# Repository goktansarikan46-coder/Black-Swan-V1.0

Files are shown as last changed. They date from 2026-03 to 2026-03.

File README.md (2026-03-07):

# Black-Swan V1.0 | Wireless Biomedical & Seismic Sensor Node

Black-Swan V1.0, saha verilerini işlemek ve uzun menzilli kablosuz ağlar üzerinden aktarmak için geliştirdigim, düşük güç tüketimli bir "Edge" sensör düğümüdür. Proje kapsamında, biyomedikal sinyal işleme (AFE) yeteneklerini savunma sanayii standartlarında RF güvenilirliği ile tek bir PCB üzerinde birlestirmeyi hedefledim.

## Teknik Özellikler

* **Mikrodenetleyici (MCU):** STM32L431RCT6 (Ultra-Low Power ARM Cortex-M4).
* **Kablosuz Haberleşme (RF):** SX1278 LoRa modülü entegrasyonu ve 50 $\Omega$ empedans uyumlu SMA anten çıkışı.
* **Analog Ön Uç (AFE):** EKG, EMG veya sismik veriler için optimize edilmiş 3-Op-Amp enstrümantasyon amplifikatörü.
* **Atalet Sensörü (IMU):** 6-eksenli hareket takibi için entegre MPU-6050.
* **Güç Yönetimi:** USB-C üzerinden besleme hattı ve gürültü regülasyonu için molded güç indüktörü (L1).

## Proje Yapısı

* `/Hardware`: KiCad şematik (.kicad_sch) ve PCB (.kicad_pcb) tasarım dosyaları.
* `/Hardware/BOM`: Malzeme listesi ve bileşen detayları.
* `/Docs`: Tasarım raporları ve 3D render görselleri.

## Tasarım Kararları

RF bütünlüğü ve analog sinyal kalitesini korumak adına genel amaçlı genişleme portlarını V2.0 sürümüne planladım.

---
**Hazırlayan:** Göktan Sarıkan (Yıldız Teknik Üniversitesi)
**Tarih:** Mart 2026

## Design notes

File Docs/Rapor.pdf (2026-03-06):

Black-Swan V1.0 | Kablosuz Biyomedikal ve Sismik Sensör Platformu

Bir süredir üzerinde çalıştığım ve tasarım süreçlerini tamamen mühürlediğim Black-Swan V1.0 projesini sonunda tamamladım. Bir biyomedikal mühendisliği öğrencisi olarak, hem tıbbi cihaz teknolojilerini hem de kablosuz haberleşme altyapısını tek bir PCB'de birleştirmeyi hedefledim.

Neyi Hedefledim?

Bu kartı tasarlarken temel amacım; sahadan gelen çok düşük genlikli analog verileri (EKG, EMG veya sismik titreşimler) yüksek hassasiyetle işleyip, LoRa teknolojisiyle kilometrelerce öteye aktarabilen bir "uç düğüm" (edge node) oluşturmaktı.

Teknik Detaylar

- Ana Kontrolcü: Düşük güç tüketimi ve performans dengesi nedeniyle STM32L431RCT6 mimarisini tercih ettim.
- Kablosuz Haberleşme: Uzun menzilli veri aktarımı için SX1278 LoRa transiver modülünü entegre ettim. Sinyal kalitesini (RF integrity) korumak adına standart buton yapılarından kaçınarak doğrudan SMA anten konnektörü kullandım.
- Analog Ön Uç (AFE): Gürültü faktörünü minimize etmek için 3-op-amp yapısında bir enstrümantasyon amplifikatörü katmanı kurguladım. Bu sayede mikrovolt seviyesindeki verileri bile stabil şekilde dijitalleştirebiliyorum.
- Hareket Takibi: Kart üzerindeki MPU-6050 ile 6-eksenli hareket verisini alarak, aktif stabilizasyon projelerim için gerekli veri akışını sağladım.
- Güç Hattı: Modernite ve dayanıklılık için USB-C girişini kullandım; hattaki gürültüyü süzmek adına da tasarıma molded güç indüktörü (L1) ekleyerek regülasyon katmanını güçlendirdim.

Tasarım ve Planlama

V1.0 sürümünde, sistemin ana fonksiyonel bloklarının (LoRa, IMU ve AFE) en yüksek stabilitede çalışmasına odaklanarak genel amaçlı genişleme portlarını bir sonraki sürüme bıraktım.

Mart 2026 itibarıyla kartın tüm elektriksel ve 3D tasarım süreçleri bitti; artık üretim ve kodlama aşamasına geçiyorum. Gelişmeleri paylaşmaya devam edeceğim.

PCB Tasarımı:

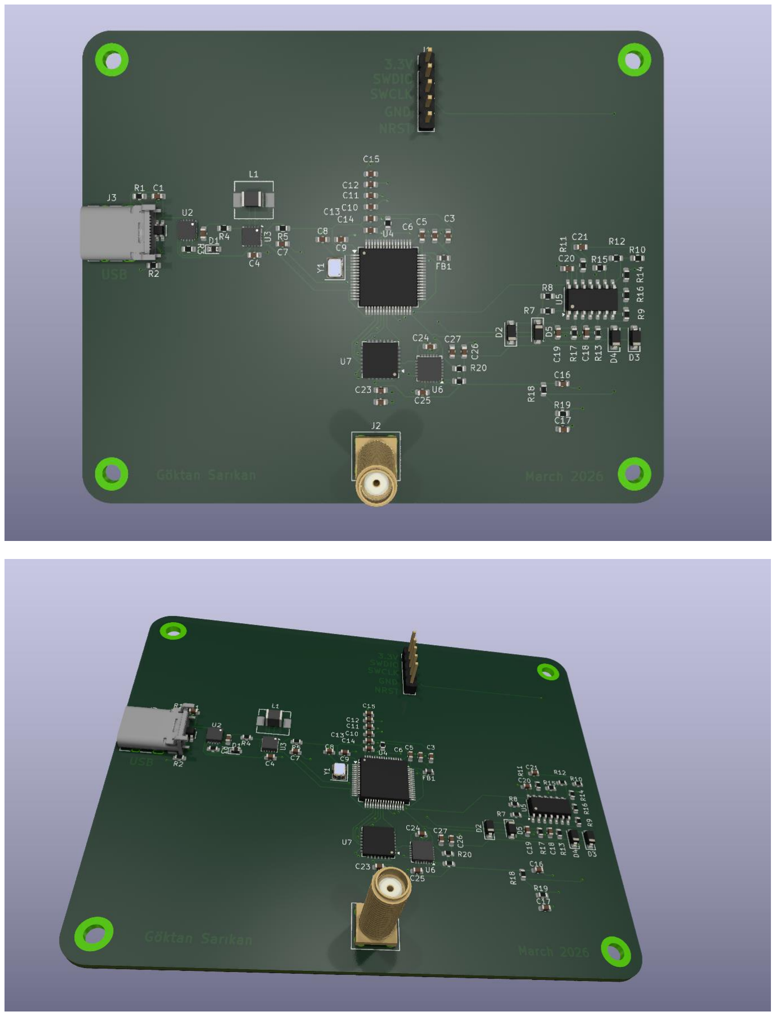
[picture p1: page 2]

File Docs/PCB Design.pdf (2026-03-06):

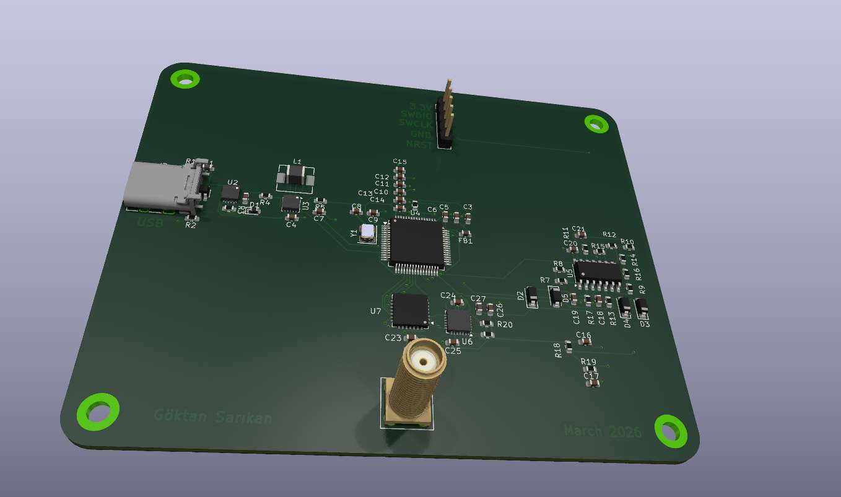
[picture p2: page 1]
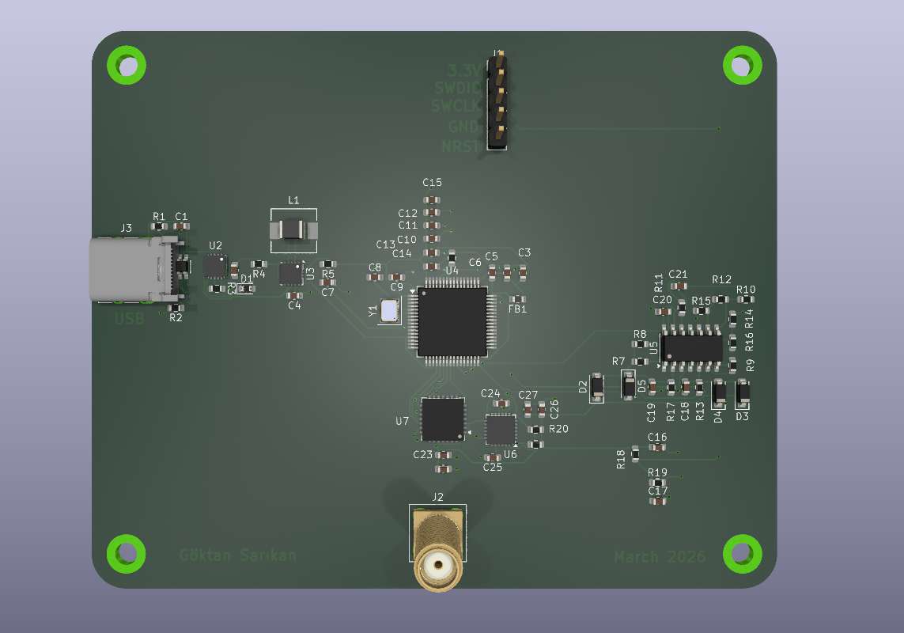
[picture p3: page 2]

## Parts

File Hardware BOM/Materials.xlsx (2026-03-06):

 | Adet | Değer / Parça No | Footprint (Kılıf) | Açıklama
U4 | 1 | STM32L431RCT6 | LQFP-64 | Ana Kontrolcü (MCU), Ultra-Low Power ARM Cortex-M4.
U7 | 1 | SX1278 | SMD Module / QFN | LoRa Kablosuz Haberleşme Modülü (433/470 MHz).
U6 | 1 | MPU-6050 | QFN-24 | 6-Eksenli İvmeölçer ve Jiroskop (IMU).
U5 | 1 | Instrumentation Amp | SOIC-14 / SOIC-16 | 3-Op-Amp Yapısında Analog Ön Uç (AFE).
L1 | 1 | Power Inductor | SMD (Molded) | USB Güç Filtreleme İndüktörü.
Y1 | 1 | Crystal | SMD-3225 | STM32 İçin Harici Kristal Osilatör.
J1 | 1 | SWD Header | 1x05 Pin Header (2.54mm) | Programlama ve Debug Arayüzü (VCC, CLK, GND, DIO, RST).
J2 | 1 | SMA Connector | SMA Edge Mount / Vertical | LoRa Anten Çıkışı (Koaksiyel).
J3 | 1 | USB-C Connector | USB-C 16-Pin | Güç Girişi ve Data Bağlantısı.
R20, R21 | 2 | 4.7k | 0603 / 0805 | I2C Hattı Pull-Up Dirençleri.
C22, C26 | 2 | 100nF | 0603 / 0805 | Dekuplaj Kapasitörleri (Seramik).
C23, C27 | 2 | 10uF | 0603 / 0805 | Güç Filtreleme Kapasitörleri (Tantal veya MLCC).
D1-D5 | 5 | 1N4148 | SOD-123 / SOD-323 | Genel Amaçlı Sinyal Diyotları.
FB1 | 1 | Ferrite Bead | O805 | Gürültü Filtreleme İçin Ferrit Boncuk.

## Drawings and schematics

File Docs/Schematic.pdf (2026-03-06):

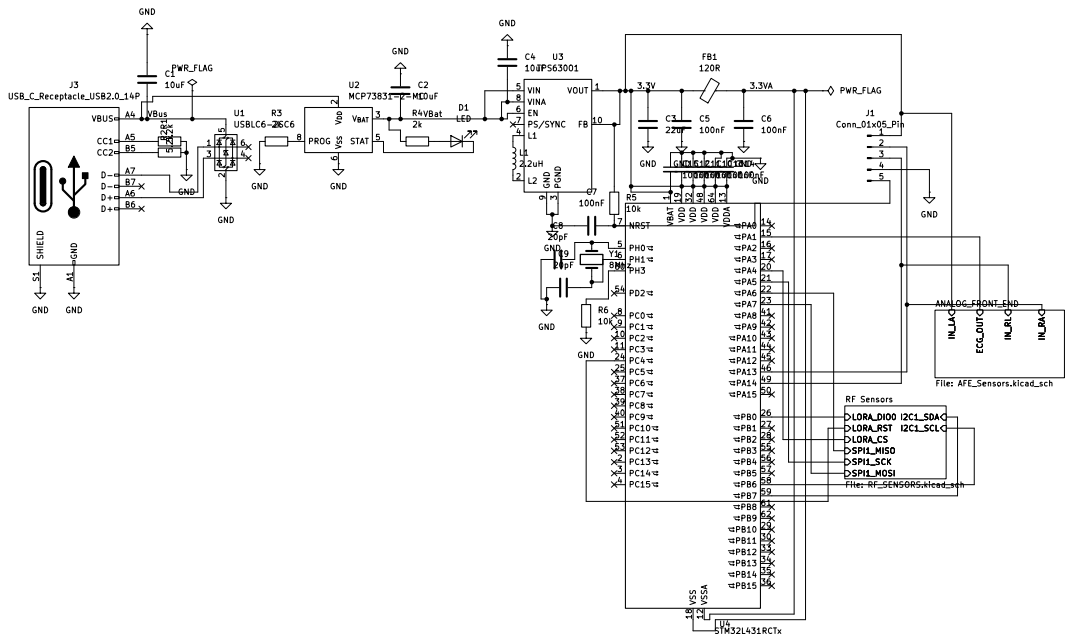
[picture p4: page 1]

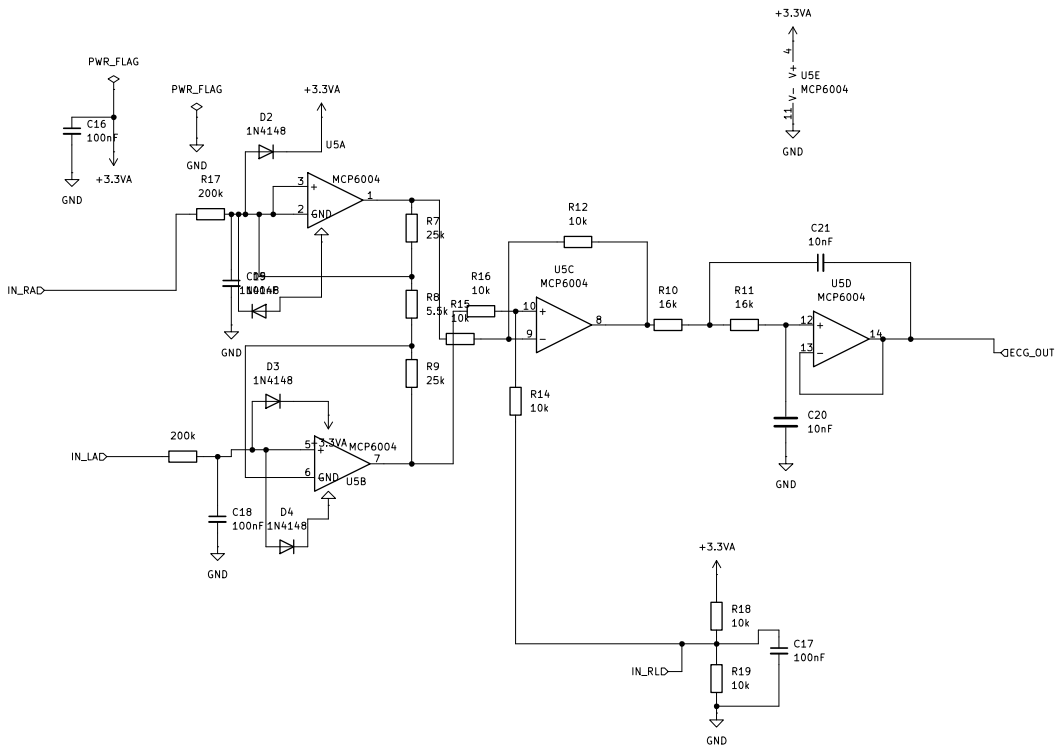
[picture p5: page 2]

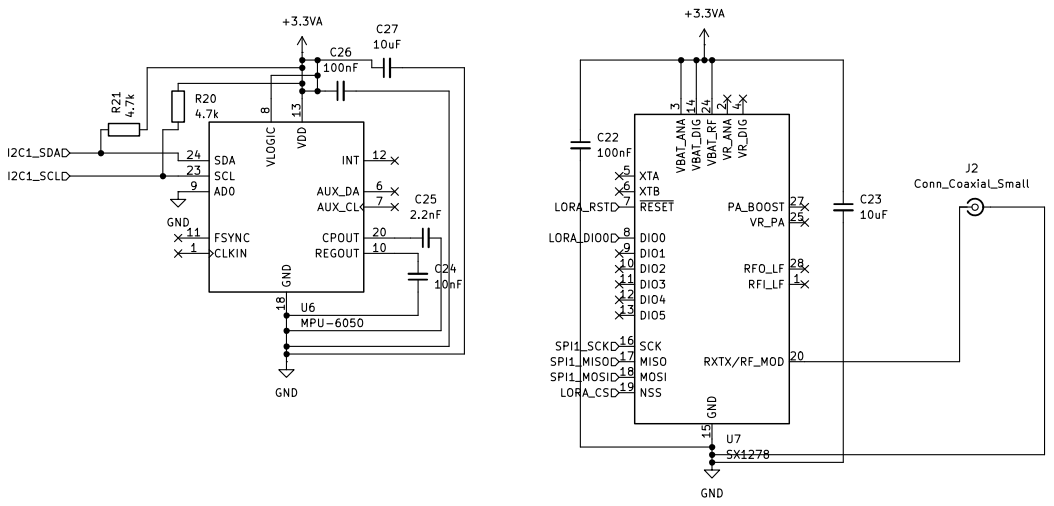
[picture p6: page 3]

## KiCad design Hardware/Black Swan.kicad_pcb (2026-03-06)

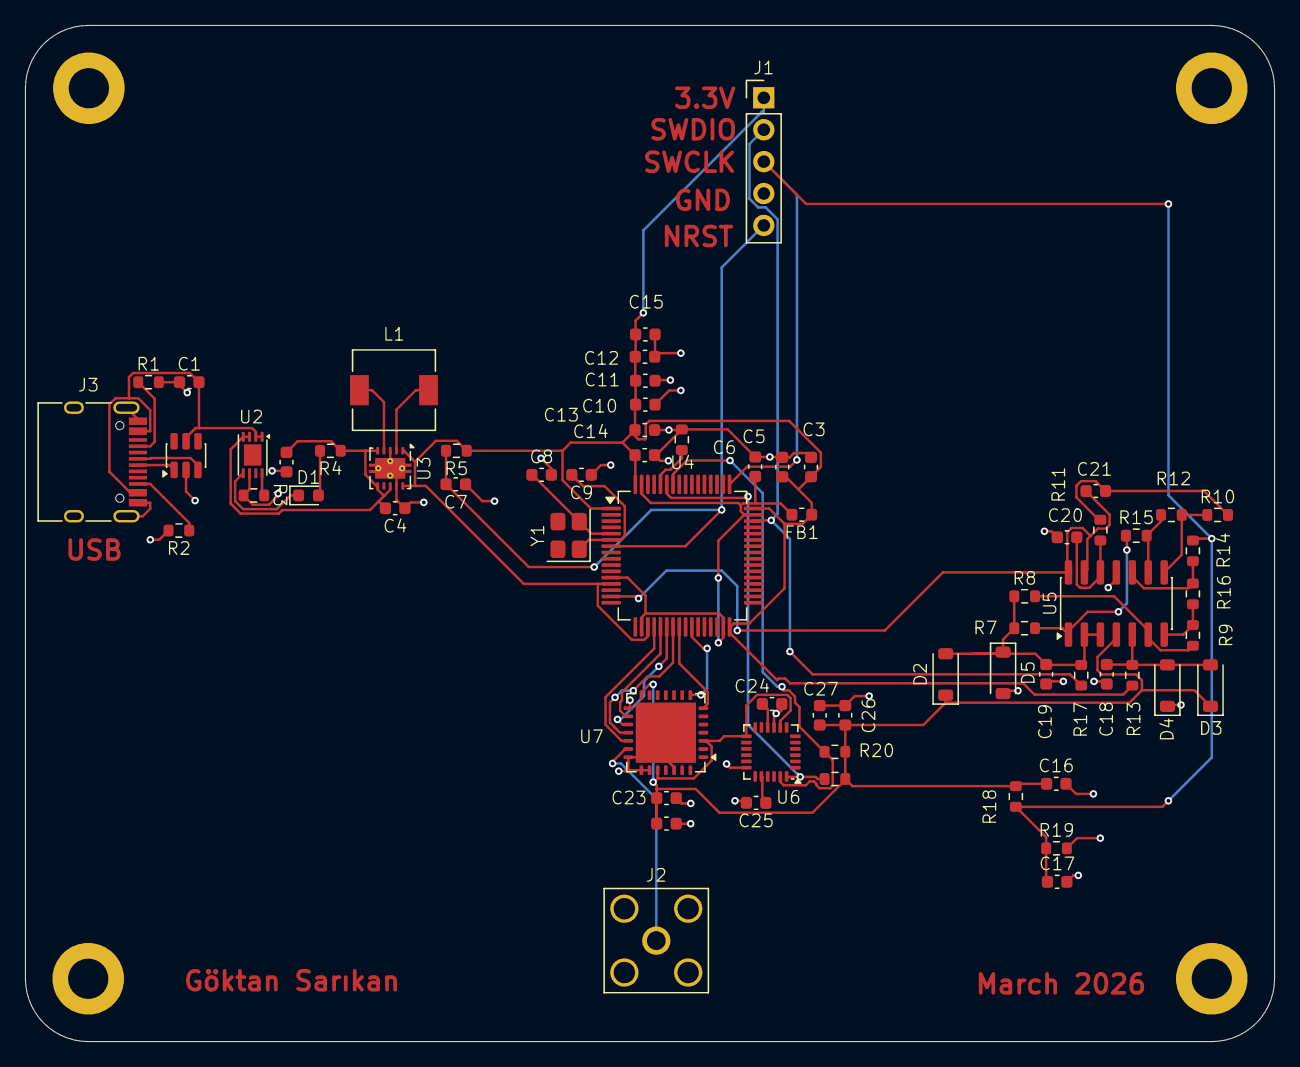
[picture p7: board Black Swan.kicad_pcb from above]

Board: 2 copper layers, 99.4 x 80.9 mm, 66 parts (0 on the bottom side), 43 nets.

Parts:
C1, C2, C4, C23, C27: 10uF; C_0603_1608Metric
C3: 22uF; C_0603_1608Metric
C5, C6, C7, C10, C11, C12, C13, C14, C15, C16, C17, C18, C19, C22, C26: 100nF; C_0603_1608Metric
C8, C9: 20pF; C_0603_1608Metric
C20, C21, C24: 10nF; C_0603_1608Metric
C25: 2.2nF; C_0603_1608Metric
D1: LED; D_0603_1608Metric
D2, D3, D4, D5: 1N4148; D_SOD-123
FB1: 120R; L_0603_1608Metric
J1: Conn_01x05_Pin; PinHeader_1x05_P2.54mm_Vertical
J2: Conn_Coaxial_Small; SMA_Amphenol_132203-12_Horizontal
J3: USB_C_Receptacle_USB2.0_14P; USB_C_Receptacle_HRO_TYPE-C-31-M-12
L1: 2.2uH; L_6.3x6.3_H3
R1, R2: 5.2k; R_0603_1608Metric
R3, R4: 2k; R_0603_1608Metric
R5, R6, R12, R14, R15, R16, R18, R19: 10k; R_0603_1608Metric
R7, R9: 25k; R_0603_1608Metric
R8: 5.5k; R_0603_1608Metric
R10, R11: 16k; R_0603_1608Metric
R13, R17: 200k; R_0603_1608Metric
R20, R21: 4.7k; R_0603_1608Metric
U1: USBLC6-2SC6; SOT-23-6
U2: MCP73831-2-MC; DFN-8-1EP_3x2mm_P0.5mm_EP1.7x1.4mm
U3: TPS63001; Texas_DRC0010J_ThermalVias
U4: STM32L431RCTx; LQFP-64_10x10mm_P0.5mm
U5: MCP6004; SOIC-14_3.9x8.7mm_P1.27mm
U6: MPU-6050; InvenSense_QFN-24_4x4mm_P0.5mm
U7: SX1278; QFN-28-1EP_6x6mm_P0.65mm_EP4.8x4.8mm
Y1: 8MHz; Crystal_SMD_3225-4Pin_3.2x2.5mm

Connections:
+3.3VA: C16.1, C22.1, C23.1, C26.1, C27.1, D2.1 (K), D3.1 (K), R18.1, R20.1, R21.2, U5.4 (V+), U6.8 (VLOGIC), U6.13 (VDD), U7.3 (VBAT_ANA), U7.14 (VBAT_DIG), U7.24 (VBAT_RF)
/3.3V: C3.1, C5.1, C10.2, C11.2, C12.2, C13.2, C14.2, C15.2, FB1.1, J1.1, R5.1, R13.1, U3.1 (VOUT), U3.10 (FB), U4.1 (VBAT), U4.13 (VDDA), U4.19 (VDD), U4.32 (VDD), U4.48 (VDD), U4.64 (VDD)
/3.3VA: C6.1, FB1.2, U4.12 (VSSA), U4.18 (VSS), U4.31 (VSS), U4.47 (VSS), U4.63 (VSS)
/ANALOG_FRONT_END/ECG_OUT: C21.2, U4.15 (PA1), U5.13 (-), U5.14
/ANALOG_FRONT_END/IN_RA: J1.2, R17.1, U4.46 (PA13)
/ANALOG_FRONT_END/IN_RL: C17.1, J1.3, R14.1, R18.2, R19.1, U4.49 (PA14)
/RF Sensors/I2C1_SCL: R20.2, U4.58 (PB6), U6.23 (SCL)
/RF Sensors/I2C1_SDA: R21.1, U4.59 (PB7), U6.24 (SDA)
/RF Sensors/LORA_CS: U4.20 (PA4), U7.19 (NSS)
/RF Sensors/LORA_DIO0: U4.26 (PB0), U7.8 (DIO0)
/RF Sensors/LORA_RST: U4.24 (PC4), U7.7 (~RESET)
/RF Sensors/SPI1_MISO: U4.22 (PA6), U7.17 (MISO)
/RF Sensors/SPI1_MOSI: U4.23 (PA7), U7.18 (MOSI)
/RF Sensors/SPI1_SCK: U4.21 (PA5), U7.16 (SCK)
/VBat: C2.2, C4.2, R4.1, U2.3 (V_{BAT}), U2.4 (V_{BAT}), U3.5 (VIN), U3.6 (EN), U3.8 (VINA)
/VBus: C1.2, J3.A4 (VBUS), J3.A9 (VBUS), J3.B4 (VBUS), J3.B9 (VBUS), U1.5 (VBUS), U2.1 (V_{DD}), U2.2 (V_{DD})
GND: C1.1, C2.1, C3.2, C4.1, C5.2, C6.2, C7.1, C8.2, C9.1, C10.1, C11.1, C12.1, C13.1, C14.1, C15.1, C16.2, C17.2, C18.2, C19.2, C20.2, C22.2, C23.2, C24.1, C25.2, C26.2, C27.2, D4.1 (K), D5.2 (A), J1.4, J2.2 (Ext), J3.A1 (GND), J3.A12 (GND), J3.B1 (GND), J3.B12 (GND), J3.S1 (SHIELD), R1.2, R2.2, R3.1, R6.2, R19.2, U1.2 (GND), U2.6 (V_{SS}), U3.3 (PGND), U3.9 (GND), U3.11 (PGND), U5.11 (V-), U6.9 (AD0), U6.18 (GND), U7.15 (GND), U7.21 (GND), U7.22 (GND), U7.23 (GND), U7.26 (GND), U7.29 (GND)
unnamed: C21.1, R10.2, R11.1
unnamed: D1.2 (A), R4.2
unnamed: D1.1 (K), U2.5 (STAT)
unnamed: C19.1, D2.2 (A), D5.1 (K), R7.2, R8.1, R17.2, U5.2 (-), U5.3 (+)
unnamed: C18.1, D3.2 (A), D4.2 (A), R13.2, U5.5 (+)
unnamed: C7.2, J1.5, R5.2, U4.7 (NRST)
unnamed: J2.1 (In), U7.20 (RXTX/RF_MOD)
unnamed: J3.A5 (CC1), R1.1
unnamed: J3.B5 (CC2), R2.1
unnamed: J3.A6 (D+), U1.3 (I/O2)
unnamed: J3.A7 (D-), U1.1 (I/O1)
unnamed: R10.1, R12.2, U5.8
unnamed: R7.1, R15.1, U5.1
unnamed: R9.2, R16.1, U5.7
unnamed: R3.2, U2.8 (PROG)
unnamed: L1.1, U3.4 (L1)
unnamed: L1.2, U3.2 (L2)
unnamed: C8.1, U4.5 (PH0), Y1.2
unnamed: C9.2, U4.6 (PH1), Y1.1
unnamed: R6.1, U4.60 (PH3)
unnamed: R8.2, R9.1, U5.6 (-)
unnamed: R14.2, R16.2, U5.10 (+)
unnamed: R12.1, R15.2, U5.9 (-)
unnamed: C20.1, R11.2, U5.12 (+)
unnamed: C25.1, U6.20 (CPOUT)
unnamed: C24.2, U6.10 (REGOUT)
